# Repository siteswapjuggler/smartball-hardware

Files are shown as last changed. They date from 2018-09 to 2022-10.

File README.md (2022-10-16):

# Smartball project - hardware 

This repository contains the Smartball project hardware files: bom, schematics, board layout and 3D printed part.

## Open Source

All the technological development work made in the Smartball project is available under open source licenses. As we don't know yet about how we will deal with further development all of our hardwares will be published under Creative Commons BY-NC-SA and all of our softwares will be under GPL v3.

|Applying to|Licence|Logo|
|---|---|---|
|hardware|[Creatives Commons BY-NC-SA](http://creativecommons.org/licenses/by-nc-sa/4.0/)||
|software|[GPL v3](http://www.gnu.org/licenses/gpl.html)|GPL V3 (http://www.gnu.org/licenses/gpl.html)|

## Different boards

The project is an assembly of three boards: 2 led boards + 1 main board. It relies on the ESP-12F espressif breakout but could be used with ESP-12E or ESP-12F without any problem.

## Version history

v1.1 is the version product for the first prototypes and contains an minor error on USB Data Lines
v1.2 is the latest version, it correct the USB Data Lines error

## Linked repositories

This repository refers directly to its following siblings : 

- https://github.com/siteswapjuggler/smartball-firmware
- https://github.com/siteswapjuggler/smartball-externals
- https://github.com/siteswapjuggler/smartball-documents
- https://github.com/siteswapjuggler/smartball-imu

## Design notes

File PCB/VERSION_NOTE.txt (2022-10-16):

v1.0 - initial release
v1.1 - USB Footprint correction for PCBWays
v1.2 - Data+ and Data- correcteds

----------------------------------------------------------------

v2.0 - 14:20 new batch
v2.1 - Jive test batch with power path and capacitor correction 
v2.2 - Jive final batch with MCP1812AT intergration and ground plane optimisation

----------------------------------------------------------------

v3.0 - prefiguration for ESP32 version

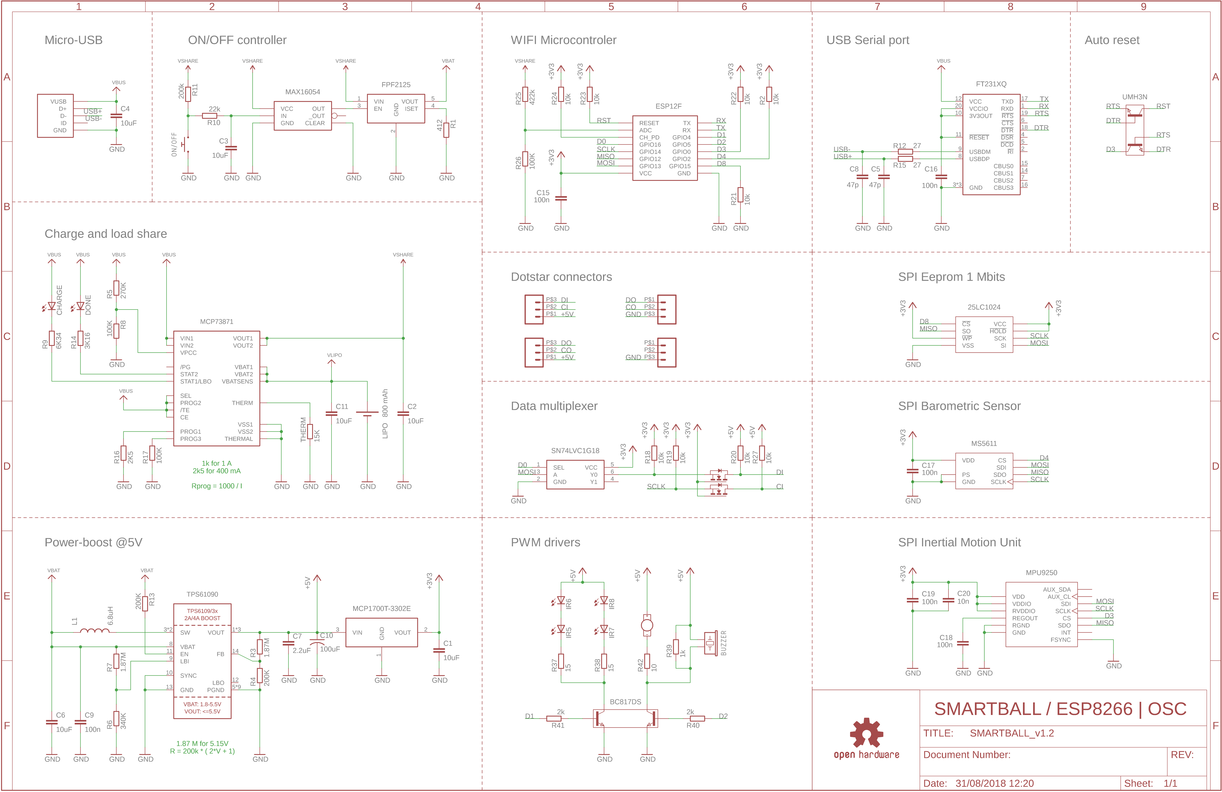
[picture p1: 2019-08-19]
PCB/docs/schematic_v1.2.png

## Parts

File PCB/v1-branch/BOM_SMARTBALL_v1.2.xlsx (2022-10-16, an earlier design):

SMARTBALL v2 - BILL OF MATERIAL
Type | Part | Value | Device | Package | NB | FOURNISSEUR | LIEN FOURNISSEUR
CHIPSET | IMU | - | MPU9250 | QFN24 | 1 | ALIEXPRESS | lien (https://fr.aliexpress.com/item/10PCS-X-100-New-INVENSENSE-MPU9250-9-AXIS-MEMS-Gyro-accelerometer-Compass-Sensor-MPU-9250/1726497480.html)
HARDWARE | BATTERY | 800 mAh | LiPo | 703035 | 1 | ALIEXPRESS | lien (https://www.aliexpress.com/item/10pcs-lot-3-7V-800mAh-703035-Lithium-Polymer-Li-Po-li-ion-Rechargeable-Battery-cells-For/32864173919.html)
HARDWARE | ESP12F | - | ESP12F | - | 1 | ALIEXPRESS | lien (https://fr.aliexpress.com/item/1PCS-Esp8266-WiFi-series-of-model-ESP-12-ESP-12F-esp12F-esp12-authenticity-guaranteed/32596555793.html)
HARDWARE | MOTOR | - | - | - | 1 | ALIEXPRESS | lien (https://fr.aliexpress.com/item/High-quality-100Pcs-10mm-x-3mm-disc-vibration-motor-vibrator-motor-game-console-handle-motor/32818196771.html)
HARDWARE | USB | - | USB_LEAD | - | 1 | ALIEXPRESS | lien (https://fr.aliexpress.com/item/25-cm-100-cm-200-cm-300-cm-Micro-USB-Rapide-Chargeur-C-ble-pour-Xiaomi/32899717419.html)
LED | LED | RGB | APA102C | 5050 | 6 | ALIEXPRESS | lien (https://fr.aliexpress.com/item/10-1000-Pieces-APA102-LEDs-Chips-APA-102C-SK9822-IC-SMD-5050-RGB-for-LED-Strip/32830624851.html)
CAPACITOR | CAPACITOR | 100 µF | TANTALUM | 1210 | 1 | FARNELL | 1432579
CAPACITOR | CAPACITOR | 10 nF | X7R | 0603 | 1 | FARNELL | 2896700
CAPACITOR | CAPACITOR | 2.2 µF | X7R | 0603 | 1 | FARNELL | 2346961
CAPACITOR | CAPACITOR | 47p | C0G / NP0 | 0603 | 2 | FARNELL | 2896692
CAPACITOR | CAPACITOR | 10 µF | X5R | 0603 | 6 | FARNELL | 2611923
CAPACITOR | CAPACITOR | 100 nF | X7R / 50V | 0603 | 6 | FARNELL | 2522435
CHIPSET | BAROMETER | - | MS5611 | QFN | - | FARNELL | 2362662
CHIPSET | BC817DS | - | BC817DS | SOT457R | 1 | FARNELL | 1757895
CHIPSET | BOOSTER | 5V | TPS61090RSAR | PVQFN-16 | 1 | FARNELL | 1207334
CHIPSET | CHARGER | 1S - 4.2V | MCP73871-2AAI | QFN20 | 1 | FARNELL | 1642487
CHIPSET | DUAL_NCH | - | 2N7002PS | SOT363 | 1 | FARNELL | 1859846
CHIPSET | DUAL_NPN | - | UMH3NFHATN | SOT363 | 1 | FARNELL | 2576211
CHIPSET | EEPROM | 1 Mbit | 25LC1024DFN-S | DFN-S | 1 | FARNELL | 1331391
CHIPSET | LATCH IC |  | MAX16054 | TSOT23-6 | 1 | FARNELL | 2515822
CHIPSET | MULTIPLEXER | 1 CH | SN74LVC1G18 | DCK | 1 | FARNELL | 2334935
CHIPSET | REGULATOR | 3V3 250 mA | MCP1700T | SOT23-3 | 1 | FARNELL | 1296592
CHIPSET | SERIAL USB | - | FT231X | QFN20 | 1 | FARNELL | 2081330
CHIPSET | SMART SWITCH | - | FPF2125 | SOT23-5 | 1 | FARNELL | 1228317
HARDWARE | BUTTON | OFF-(ON) | B3U-3000P-B | - | 1 | FARNELL | 1333656
HARDWARE | BUZZER | 4000 Hz | PKMCS0909E4000-R1 | - | 1 | FARNELL | 2529461
HARDWARE | USB | - | MOLEX_105017-0001 | - | 1 | FARNELL | 2293836
INDUCTOR | INDUCTOR | 6.8uH | ASPIAIG-S4035-6R8M-T | - | 1 | FARNELL | 2848352
LED | LED | Green |  | 0603 | 1 | FARNELL | 2099223
LED | LED | Orange |  | 0603 | 1 | FARNELL | 2099222
LED | LED | 850 nm | SFH4050 | - | 4 | FARNELL | 1441335
RESISTOR | RESISTOR | 412 | R-EU_R0402 | 0402 | 1 | FARNELL | 2302592
RESISTOR | RESISTOR | 15K | R-EU_R0402 | 0402 | 1 | FARNELL | 2302754
RESISTOR | RESISTOR | 22K | R-EU_R0402 | 0402 | 1 | FARNELL | 2302772
RESISTOR | RESISTOR | 270K | R-EU_R0402 | 0402 | 1 | FARNELL | 2302885
RESISTOR | RESISTOR | 2K55 | R-EU_R0402 | 0402 | 1 | FARNELL | 2302679
RESISTOR | RESISTOR | 340K | R-EU_R0402 | 0402 | 1 | FARNELL | 2694598
RESISTOR | RESISTOR | 3K16 | R-EU_R0402 | 0402 | 1 | FARNELL | 2302687
RESISTOR | RESISTOR | 422K | R-EU_R0402 | 0402 | 1 | FARNELL | 2302909
RESISTOR | RESISTOR | 6K34 | R-EU_R0402 | 0402 | 1 | FARNELL | 2302721
RESISTOR | RESISTOR | 10 / 250 mW | R-EU_R0402 | 0402 | 1 | FARNELL | 2502794
RESISTOR | RESISTOR | 1K | R-EU_R0402 | 0402 | 1 | FARNELL | 2302638
RESISTOR | RESISTOR | 27 | R-EU_R0402 | 0402 | 2 | FARNELL | 2302462
RESISTOR | RESISTOR | 1M87 / 1% | R-EU_R0402 | 0402 | 2 | FARNELL | 2141071
RESISTOR | RESISTOR | 15 / 125 mW | R-EU_R0402 | 0402 | 2 | FARNELL | 1738826
RESISTOR | RESISTOR | 2K | R-EU_R0402 | 0402 | 2 | FARNELL | 2059132
RESISTOR | RESISTOR | 100K | R-EU_R0402 | 0402 | 3 | FARNELL | 2302839
RESISTOR | RESISTOR | 200K | R-EU_R0402 | 0402 | 3 | FARNELL | 2059185
RESISTOR | RESISTOR | 10K | R-EU_R0402 | 0402 | 9 | FARNELL | 2302739
TOOLS | GLUE | - | LOCTITE 406 | - | 1 | FARNELL | 1370126
TOOLS | GLUE | - | LOCTITE 770 | - | 1 | FARNELL | 1370163
HARDWARE | HARDWARE | - | COQUE_BALLE | - | 1 | LA RIBOULDINGUE | -
HARDWARE | PCB | - | MAIN_PCB | - | 1 | PCB_WAY | lien (https://www.pcbway.com/)
HARDWARE | PCB | - | LED_PCB | - | 2 | PCB_WAY | lien (https://www.pcbway.com/)
HARDWARE | FEMALE_HEADER | 2 mm | SAMTEC SMM-103-02-S-S | SMD | 4 | SAMTEC | lien (https://www.samtec.com/products/smm)
HARDWARE | MALE_HEADER | 2 mm | SAMTEC TW-03-02-T-S-150-120 | TH | 4 | SAMTEC | lien (https://www.samtec.com/products/tw-th)
HARDWARE | 3D_PRINT | - | SUPPORT_PCB | - | 1 | SELF_PRODUCTION | -
HARDWARE | 3D_PRINT | - | SUPPORT_LEDS | - | 2 | SELF_PRODUCTION | -
 | Total |  |  |  | 100

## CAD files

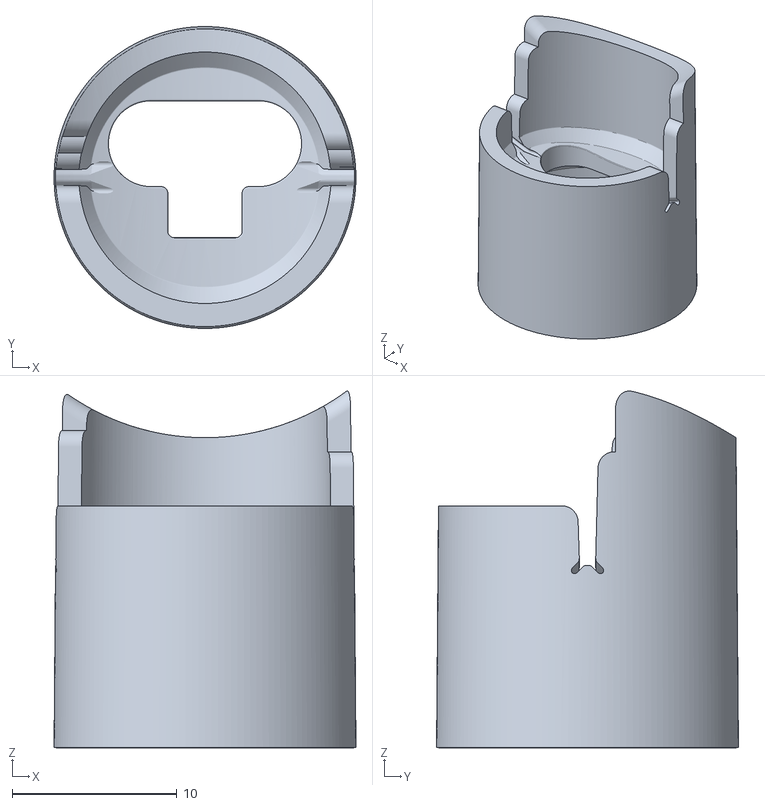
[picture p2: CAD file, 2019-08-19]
STL/pcb_support_v5.stl
18.3 x 18.3 x 21.6

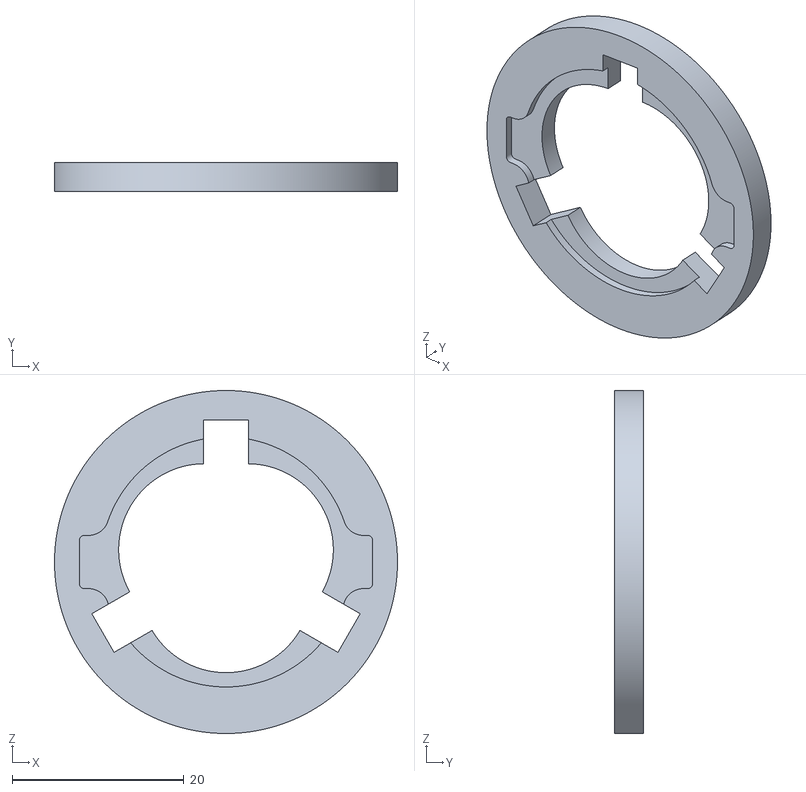
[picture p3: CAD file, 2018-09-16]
STL/led_placement.stl
40.0 x 3.40 x 40.0

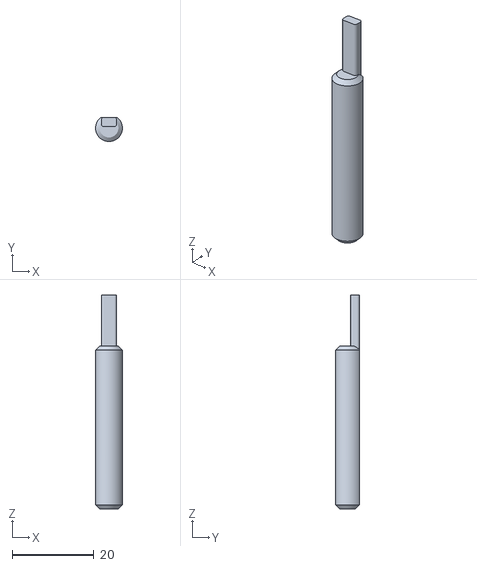
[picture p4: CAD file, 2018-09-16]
STL/starter_tool.stl
6.60 x 5.90 x 52.5

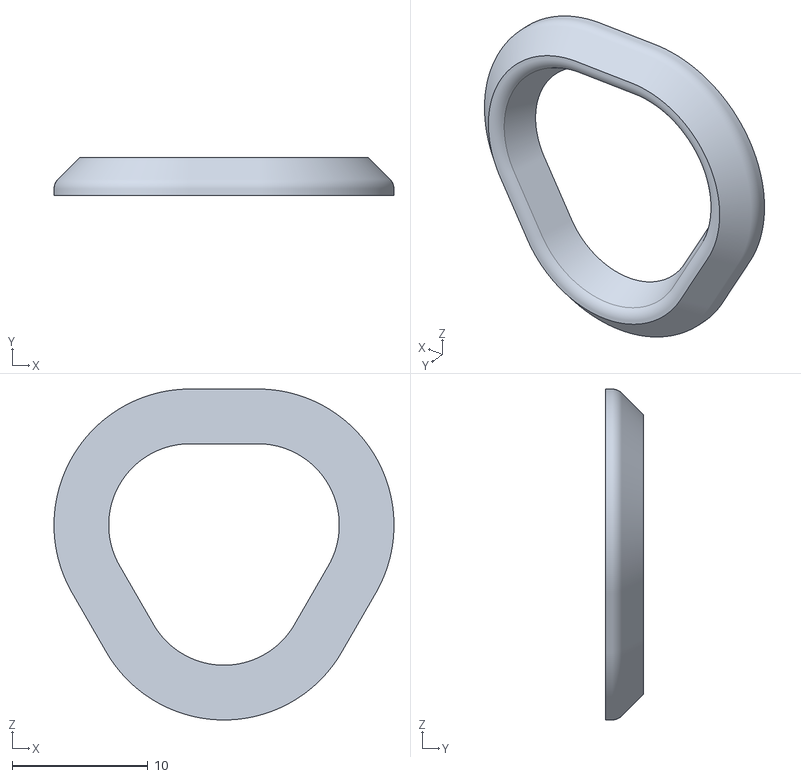
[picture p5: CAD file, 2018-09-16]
STL/leds_support.stl
25.0 x 2.83 x 24.4

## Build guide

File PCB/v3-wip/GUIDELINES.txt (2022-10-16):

USB-C
MAX1650 Power Management
Better Buck Boost Converter and 3V3 LDO
FPC for APA107 and IR Leds
Better selection for motor and buzzer
New IMU because of MPU9255 not being available anymore
Optimised Antenna
ESP32

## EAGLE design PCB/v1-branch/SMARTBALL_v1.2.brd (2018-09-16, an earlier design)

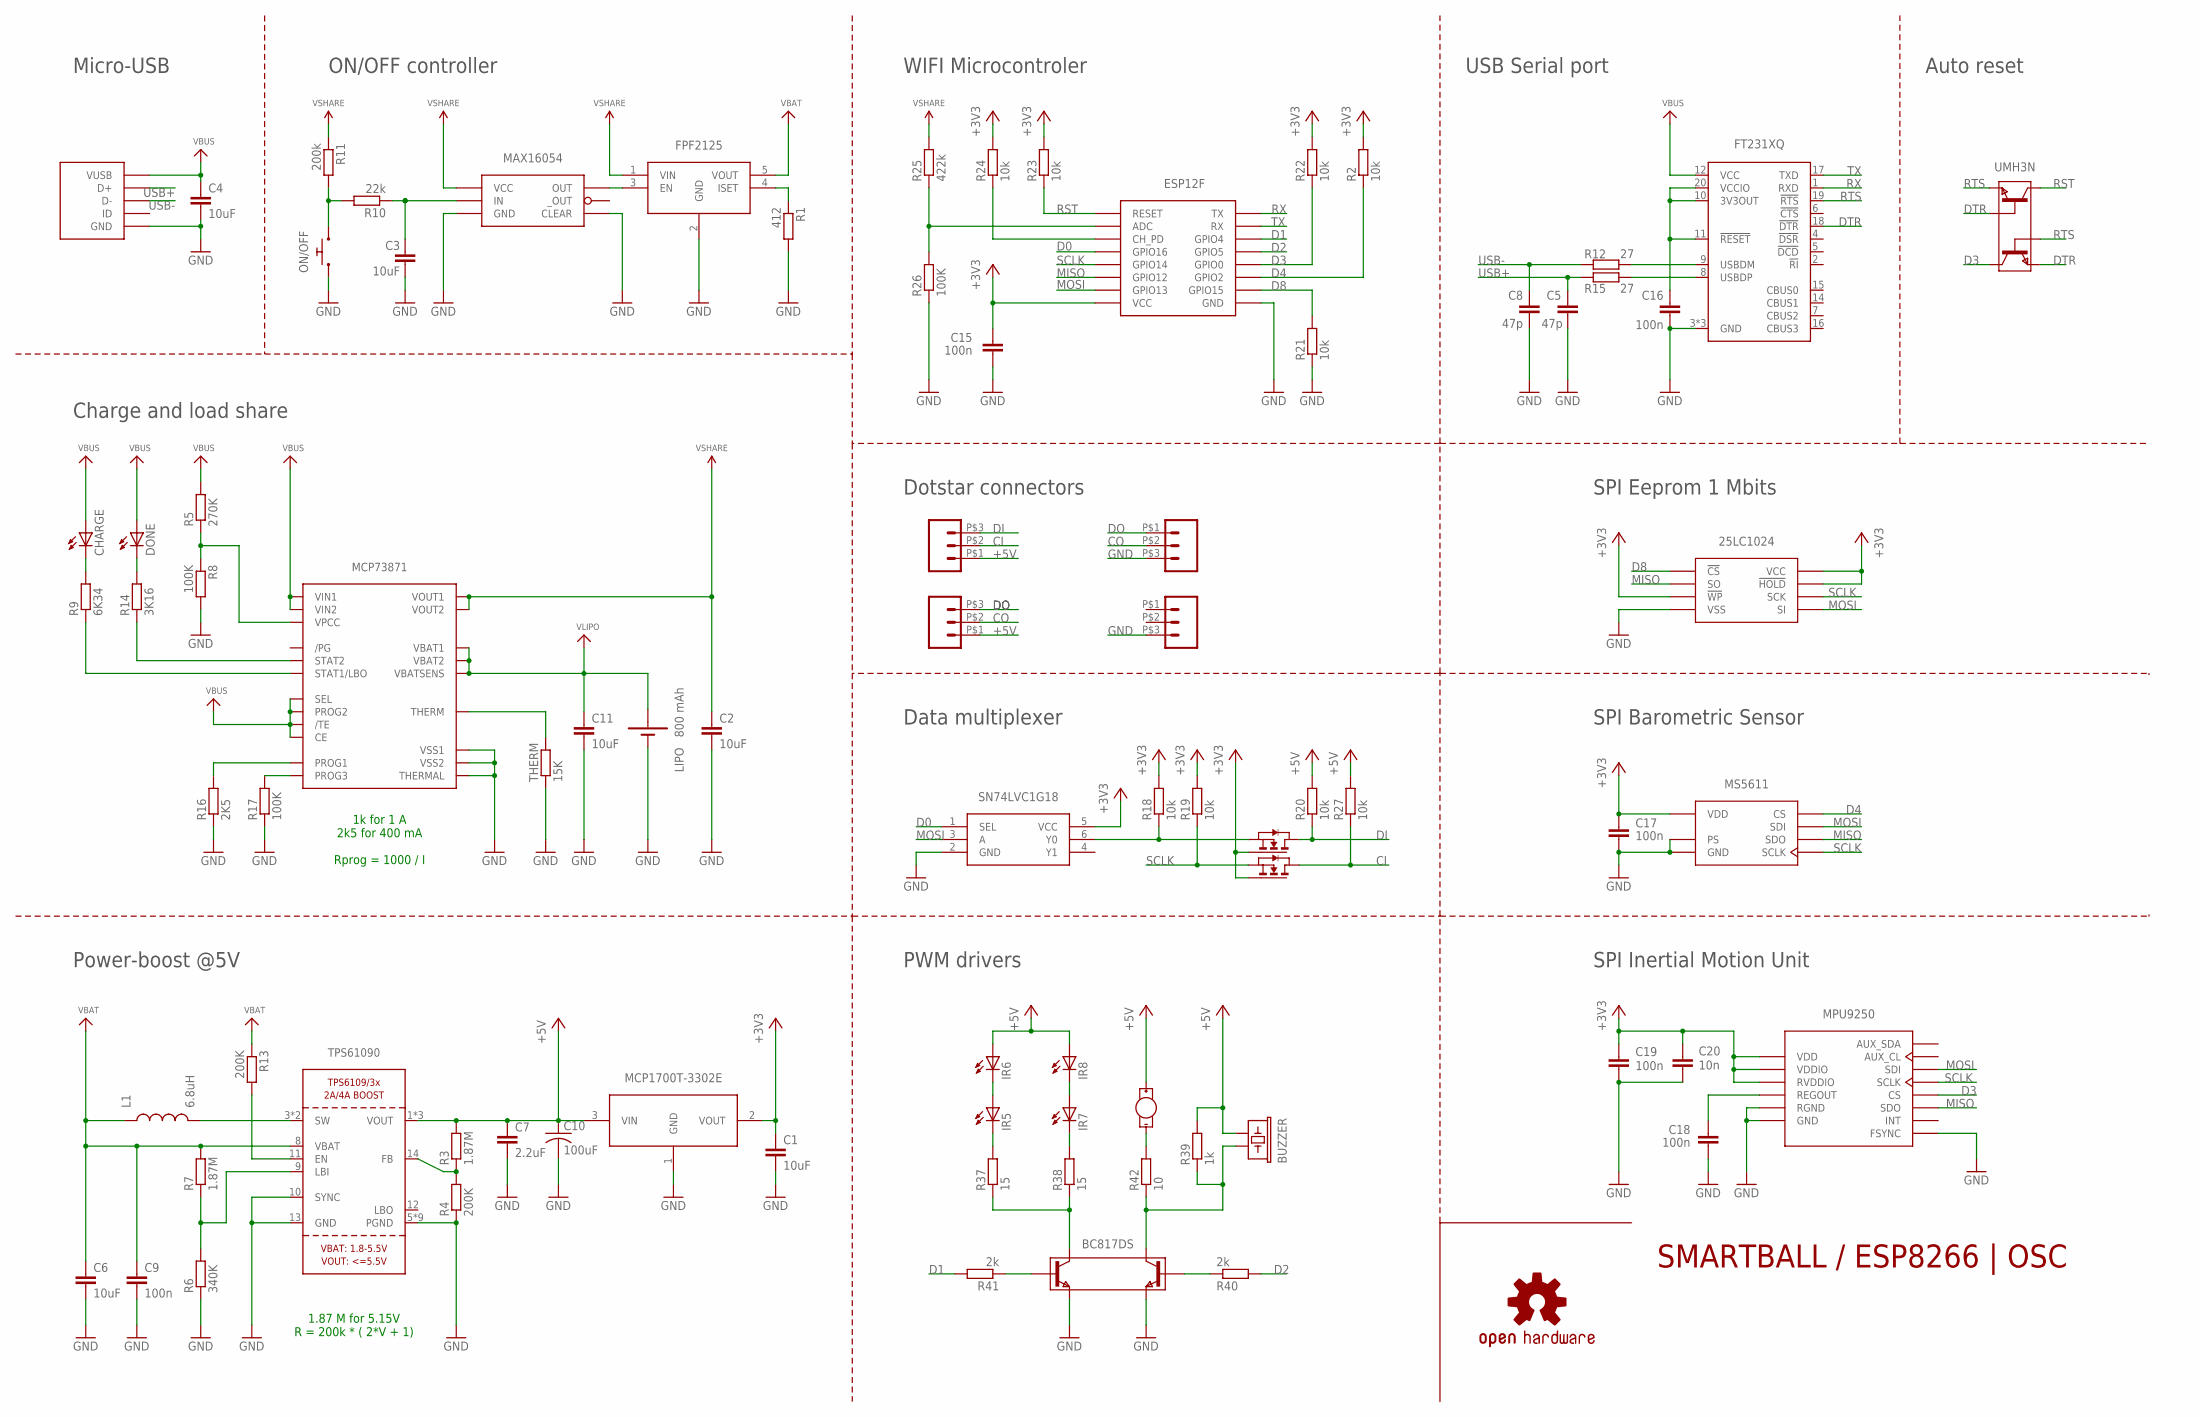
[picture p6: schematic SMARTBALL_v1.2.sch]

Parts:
BC817DS: BC817DS; SOT457R_PHILIPS
BUZZER: BUZZER_PKMCS0909E4000-R1
C1, C2, C3, C4, C6, C11: 10uF; C0603K
C5, C8: 47p; C0603K
C7: 2.2uF; C0603K
C9, C15, C16, C17, C18, C19: 100n; C0603K
C10: 100uF; C1210
C20: 10n; C0603K
CHARGE: KINGBRIGHT_16X08
DONE: KINGBRIGHT_16X08
ESP12F: ESP12
FT231XQ: FT231X; QFN20
IR5, IR6, IR7, IR8: LED-SFH4050; SFH4050
L1: 6.8uH; ASPIAIG-S4035
LIPO: BATTERY_CONNECTOR; MOTOR_CONNECTOR
LOGO1: OSHW-LOGOL; OSHW-LOGO-L
MCP73871: MCP73871; QFN20_4MM
MOTOR: MOTOR_CONNECTOR
ON/OFF: B3U-3000P-B
R1: 412; R0402
R2, R18, R19, R20, R21, R22, R23, R24, R27: 10k; R0402
R3, R7: 1.87M; R0402
R4, R13: 200K; R0402
R5: 270K; R0402
R6: 340K; R0402
R8, R17, R26: 100K; R0402
R9: 6K34; R0402
R10: 22k; R0402
R11: 200k; R0402
R12, R15: 27; R0402
R14: 3K16; R0402
R16: 2K5; R0402
R25: 422k; R0402
R37, R38: 15; R0402
R39: 1k; R0402
R40, R41: 2k; R0402
R42: 10; R0402
THERM: 15K; R0402
TPS61090: TPS61090RSAR; PVQFN-16
U$1: MOLEX-USB
U$2: FPF2125; SOT23-5
U$3: MCP1700T; SOT23-3
U$5, U$6, U$14, U$15: CONN_03_SMD; CONN03_SMD
U$12: MAX16054; TSOT23-6
U$16: 25LC1024DFN-S; DFN-S
U$17: MS5611; MS5611-QFN
U$20: SN74LVC1G18; DCK_R-PDSO-G6
U$21: MPU-9250QFN24G; QFN24G-0.4-3X3MM
U$22: 2N7002PS; SOT363_PHILIPS
UMH3N: UMH3N; SOT363_PHILIPS

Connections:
+3V3: C1.1, C15.1, C17.1, C19.1, C20.2, ESP12F.VCC, R2.2, R18.2, R19.2, R22.2, R23.2, R24.2, U$3.2 (VOUT), U$16.3 (!WP), U$16.7 (!HOLD), U$16.8 (VCC), U$17.P$1 (VDD), U$20.5 (VCC), U$21.1 (RVDDIO), U$21.8 (VDDIO), U$21.13 (VDD), U$22.2 (G1), U$22.5 (G2)
+5V: BUZZER.P$1 (1), C7.1, C10.1, IR6.P$1 (A), IR8.P$1 (A), MOTOR.+, R3.2, R20.2, R27.2, R39.2, TPS61090.1 (VOUT), TPS61090.15 (VOUT), TPS61090.16 (VOUT), U$3.3 (VIN), U$5.P$1 (1), U$15.P$1 (1)
CI: R27.1, U$5.P$2 (2), U$22.3 (D2)
CO: U$6.P$2 (2), U$15.P$2 (2)
D0: ESP12F.GPIO16, U$20.1 (SEL)
D1: ESP12F.GPIO4, R41.2
D2: ESP12F.GPIO5, R40.2
D3: ESP12F.GPIO0, R22.1, U$21.22 (CS), UMH3N.3 (C2)
D4: ESP12F.GPIO2, R2.1, U$17.P$4 (CS), U$17.P$5 (CS)
D8: ESP12F.GPIO15, R21.2, U$16.1 (!CS)
DI: R20.1, U$5.P$3 (3), U$22.6 (D1)
DO: U$6.P$1 (1), U$15.P$3 (3)
DTR: FT231XQ.18 (!DTR), UMH3N.2 (B1), UMH3N.4 (E2)
EN1: ESP12F.CH_PD, R24.1
ENABLE: R13.2, TPS61090.11 (EN)
GND: BC817DS.1 (E1), BC817DS.4 (E2), C1.2, C2.2, C3.2, C4.2, C5.2, C6.2, C7.2, C8.2, C9.2, C10.2, C11.2, C15.2, C16.2, C17.2, C18.2, C19.2, C20.1, ESP12F.GND, FT231XQ.3 (GND), FT231XQ.13 (GND), FT231XQ.EXP (GND), LIPO.-, MCP73871.P$10 (VSS1), MCP73871.P$11 (VSS2), MCP73871.P$21 (THERMAL), ON/OFF.P$1 (1), R1.2, R4.1, R6.1, R8.2, R16.1, R17.1, R21.1, R26.1, THERM.1, TPS61090.5 (PGND), TPS61090.6 (PGND), TPS61090.7 (PGND), TPS61090.10 (SYNC), TPS61090.13 (GND), TPS61090.P$18 (PGND), TPS61090.P$19 (PGND), TPS61090.P$20 (PGND), TPS61090.P$21 (PGND), TPS61090.P$22 (PGND), TPS61090.THERMAL (PGND), U$1.GND, U$1.P$1 (GND), U$1.P$11 (GND), U$1.SHELL1 (GND), U$1.SHELL2 (GND), U$1.SHELL5 (GND), U$1.SHELL6 (GND), U$2.2 (GND), U$3.1 (GND), U$6.P$3 (3), U$12.CLEAR, U$12.GND, U$14.P$3 (3), U$16.4 (VSS), U$17.P$2 (PS), U$17.P$3 (GND), U$20.2 (GND), U$21.11 (FSYNC), U$21.18 (GND), U$21.20 (RGND)
MISO: ESP12F.GPIO12, U$16.2 (SO), U$17.P$6 (SDO), U$21.9 (SDO)
MOSI: ESP12F.GPIO13, U$16.5 (SI), U$17.P$7 (SDI), U$20.3 (A), U$21.24 (SDI)
unnamed: U$2.3 (EN), U$12.OUT
unnamed: R1.1, U$2.4 (ISET)
unnamed: MCP73871.P$2 (VPCC), R5.1, R8.1
unnamed: MCP73871.P$13 (PROG1), R16.2
unnamed: FT231XQ.9 (USBDM), R12.2
unnamed: FT231XQ.8 (USBDP), R15.2
unnamed: ON/OFF.P$2 (2), R10.2, R11.2
unnamed: C3.1, R10.1, U$12.IN
unnamed: R18.1, U$20.6 (Y0), U$22.1 (S1)
unnamed: ESP12F.ADC, R25.1, R26.2
unnamed: L1.P$2 (2), TPS61090.3 (SW), TPS61090.4 (SW)
unnamed: R6.2, R7.1, TPS61090.9 (LBI)
unnamed: R3.1, R4.2, TPS61090.14 (FB)
unnamed: MCP73871.P$7 (STAT2), R14.1
unnamed: MCP73871.P$8 (STAT1/LBO), R9.1
unnamed: MCP73871.P$5 (THERM), THERM.2
unnamed: DONE.CATHODE (C), R14.2
unnamed: CHARGE.CATHODE (C), R9.2
unnamed: MCP73871.P$12 (PROG3), R17.2
unnamed: IR5.P$2 (C), R37.2
unnamed: IR5.P$1 (A), IR6.P$2 (C)
unnamed: BC817DS.3 (C2), R37.1, R38.1
unnamed: IR7.P$2 (C), R38.2
unnamed: IR7.P$1 (A), IR8.P$2 (C)
unnamed: BC817DS.6 (C1), BUZZER.P$2 (2), R39.1, R42.1
unnamed: MOTOR.-, R42.2
unnamed: BC817DS.5 (B2), R41.1
unnamed: BC817DS.2 (B1), R40.1
REGOUT1: C18.1, U$21.10 (REGOUT)
RST: ESP12F.RESET, R23.1, UMH3N.6 (C1)
RTS: FT231XQ.19 (!RTS), UMH3N.1 (E1), UMH3N.5 (B2)
RX: ESP12F.TX, FT231XQ.1 (RXD)
SCLK: ESP12F.GPIO14, R19.1, U$16.6 (SCK), U$17.P$8 (SCLK), U$21.23 (SCLK), U$22.4 (S2)
TX: ESP12F.RX, FT231XQ.17 (TXD)
USB+: C5.1, R15.1, U$1.D+
USB-: C8.1, R12.1, U$1.D-
VBAT: C6.1, C9.1, L1.P$1 (1), R7.2, R13.1, TPS61090.8 (VBAT), U$2.5 (VOUT)
VBUS: C4.1, CHARGE.ANODE (A), DONE.ANODE (A), FT231XQ.12 (VCC), MCP73871.P$3 (SEL), MCP73871.P$4 (PROG2), MCP73871.P$9 (/TE), MCP73871.P$17 (CE), MCP73871.P$18 (VIN1), MCP73871.P$19 (VIN2), R5.2, U$1.VUSB
VCCIO1: C16.1, FT231XQ.10 (3V3OUT), FT231XQ.11 (!RESET), FT231XQ.20 (VCCIO)
VLIPO: C11.1, LIPO.+, MCP73871.P$14 (VBAT1), MCP73871.P$15 (VBAT2), MCP73871.P$16 (VBATSENS)
VSHARE: C2.1, MCP73871.P$1 (VOUT1), MCP73871.P$20 (VOUT2), R11.1, R25.2, U$2.1 (VIN), U$12.VCC

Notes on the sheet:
SMARTBALL / ESP8266 | OSC
MCP1700T-3302E
1k for 1 A 2k5 for 400 mA Rprog = 1000 / I
Micro-USB
Charge and load share
ON/OFF controller
USB Serial port
WIFI Microcontroler
Auto reset
Data multiplexer
Dotstar connectors
PWM drivers
Power-boost @5V
SPI Inertial Motion Unit
SPI Eeprom 1 Mbits
SPI Barometric Sensor
800 mAh
MAX16054
FPF2125
SN74LVC1G18
1.87 M for 5.15V R = 200k * ( 2*V + 1)

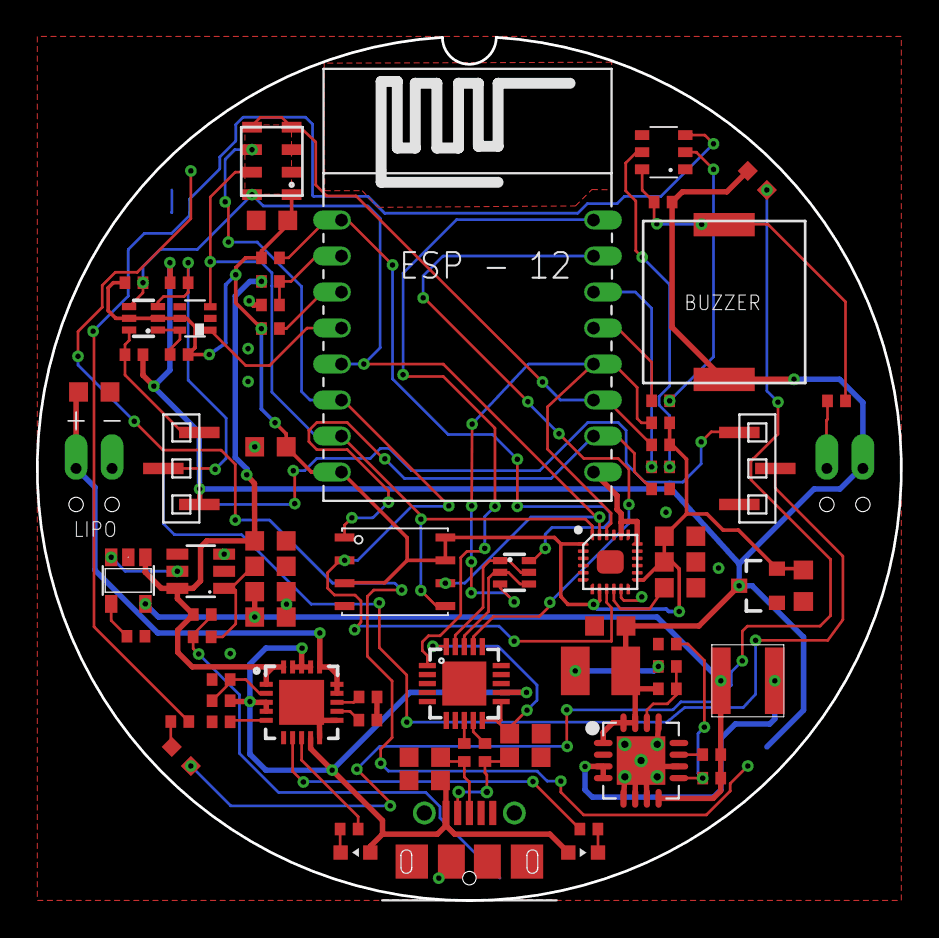
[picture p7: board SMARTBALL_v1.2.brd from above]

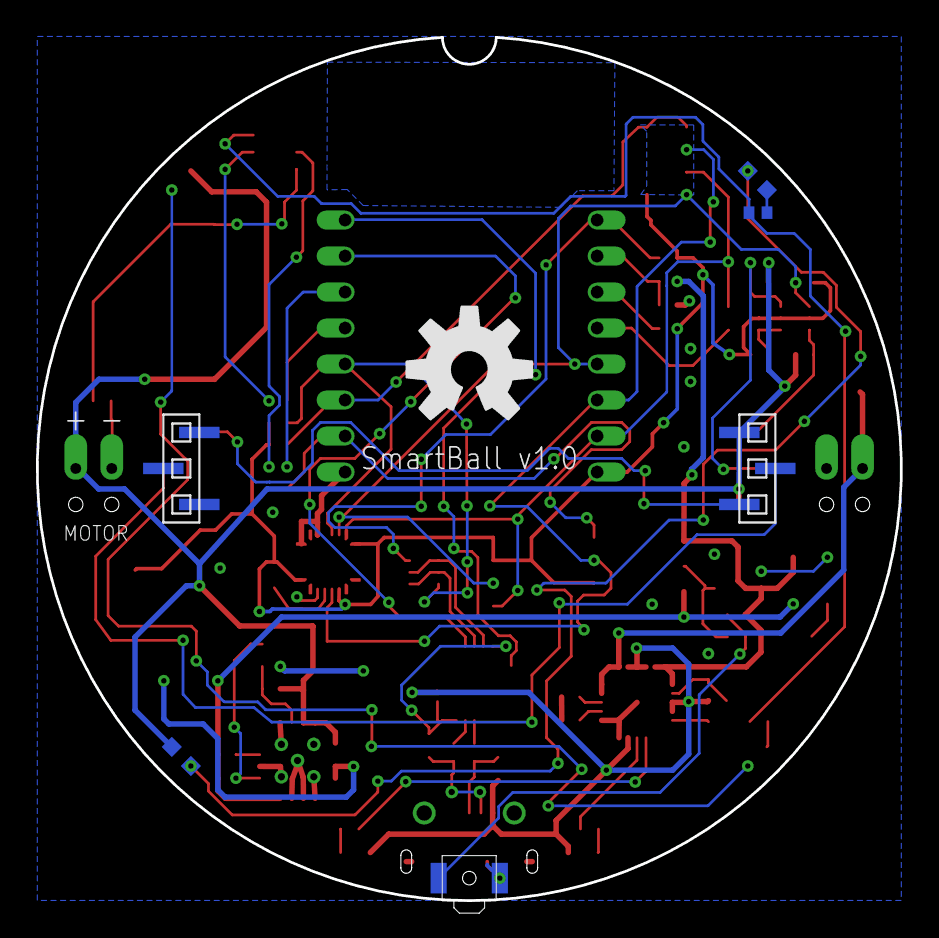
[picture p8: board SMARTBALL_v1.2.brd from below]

Board: 2 copper layers, 48.0 x 48.0 mm, 82 parts (8 on the bottom side), 59 nets.

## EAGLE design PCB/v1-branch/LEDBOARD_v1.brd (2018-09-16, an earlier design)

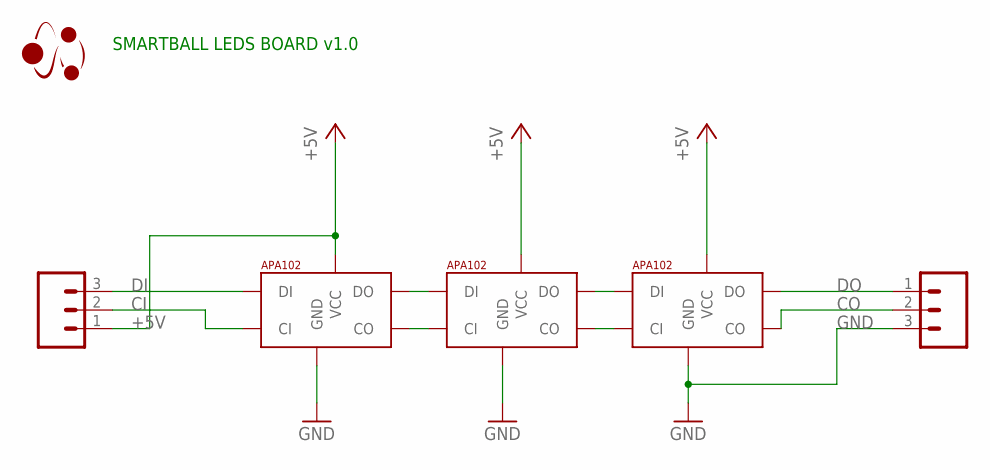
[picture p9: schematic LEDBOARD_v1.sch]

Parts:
U$1, U$2, U$3: APA102; APA102_5050_SB
U$4: LOGO_SMARTBALL; SMARTBALL_LOGO
U$5, U$6: CONN_03_SMDCONN03_SMD_MALE; CONN03_SMD_MALE

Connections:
+5V: U$1.VCC, U$2.VCC, U$3.VCC, U$5.1
CI: U$1.CI, U$1.CI2 (CI), U$5.2
CO: U$3.CO, U$6.2
DI: U$1.DI, U$1.DI2 (DI), U$5.3
DO: U$3.DO, U$6.1
GND: U$1.GND, U$1.GND2 (GND), U$2.GND, U$2.GND2 (GND), U$3.GND, U$3.GND2 (GND), U$6.3
unnamed: U$1.DO, U$2.DI, U$2.DI2 (DI)
unnamed: U$1.CO, U$2.CI, U$2.CI2 (CI)
unnamed: U$2.DO, U$3.DI, U$3.DI2 (DI)
unnamed: U$2.CO, U$3.CI, U$3.CI2 (CI)

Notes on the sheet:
SMARTBALL LEDS BOARD v1.0

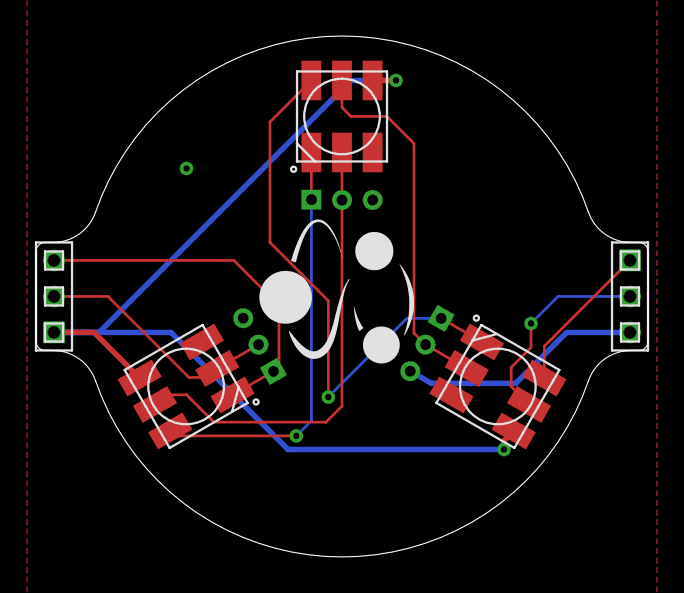
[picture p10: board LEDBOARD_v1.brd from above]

Board: 2 copper layers, 34.0 x 28.9 mm, 6 parts (0 on the bottom side), 10 nets.

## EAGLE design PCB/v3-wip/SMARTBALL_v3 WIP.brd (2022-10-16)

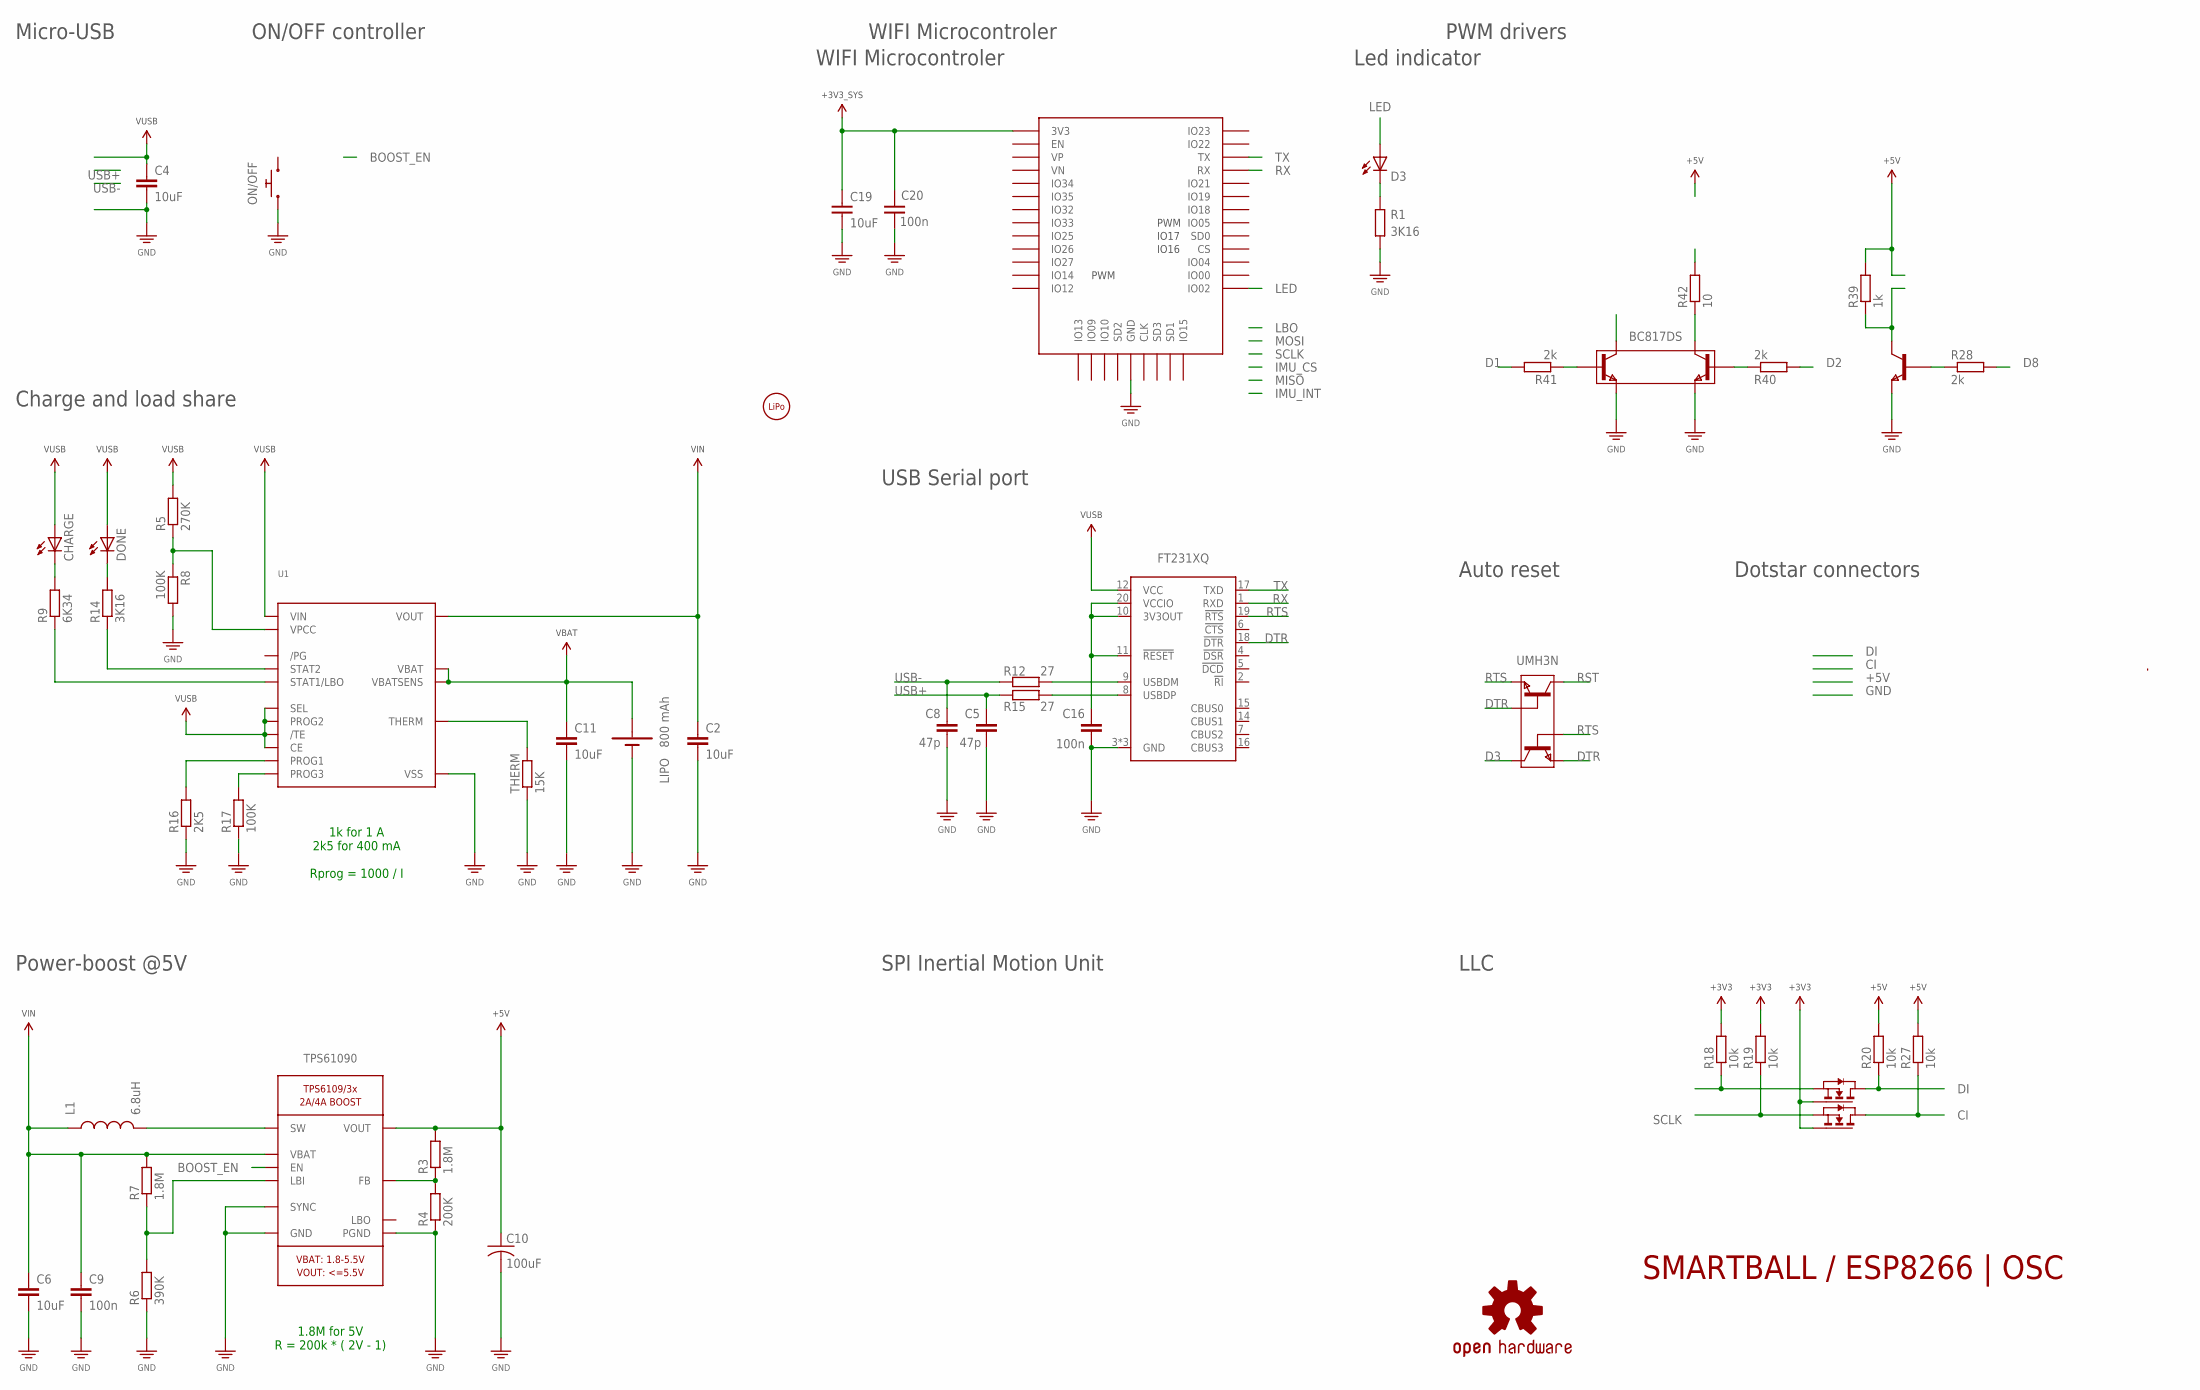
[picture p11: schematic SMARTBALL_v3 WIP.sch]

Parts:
BC817DS: SOT_BC817DS; SOT457R_PHILIPS
C2, C4, C6, C11, C19: 10uF; C0603
C5, C8: 47p; C0603
C9, C16, C20: 100n; C0603
C10: 100uF; C1210
CHARGE: LED_KINGBRIGHT_16X08
D3: Blue; LED_KINGBRIGHT_16X08
DONE: LED_KINGBRIGHT_16X08
FT231XQ: QFN_FT231X; QFN20
L1: 6.8uH; IND_ASPIAIG-S4035
LIPO: CONN_BATTERY; CONN_WIRES
LOGO1: LOGO_OSHWL; LOGO_OSHW
ON/OFF: BUT_KMR6
R1, R14: 3K16; R0402
R3, R7: 1.8M; R0402
R4: 200K; R0402
R5: 270K; R0402
R6: 390K; R0402
R8, R17: 100K; R0402
R9: 6K34; R0402
R12, R15: 27; R0402
R16: 2K5; R0402
R18, R19, R20, R27: 10k; R0402
R28, R40, R41: 2k; R0402
R39: 1k; R0402
R42: 10; R0402
THERM: 15K; R0402
TPS61090: TPS61090RSAR; QFN16
U1: QFN_MCP73871; QFN20
U6: ESP-MICRO32
U$22: SOT_2N7002PS; SOT363
U$28: SOT_SBC847AWT1G; SOT323
U$29: BATT_BODY
UMH3N: SOT_UMH3N; SOT363

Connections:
+3V3: R18.2, R19.2, U$22.2 (G1), U$22.5 (G2)
+3V3_SYS: C19.1, C20.1, U6.2 (3V3)
+5V: C10.1, R3.2, R20.2, R27.2, R39.2, TPS61090.1 (VOUT), TPS61090.15 (VOUT), TPS61090.16 (VOUT)
B1: BC817DS.5 (B2), R41.1
B2: BC817DS.2 (B1), R40.1
B3: R28.1, U$28.1 (B)
BOOST_EN: TPS61090.11 (EN)
C1: BC817DS.3 (C2)
C2: BC817DS.6 (C1), R42.1
C3: R39.1, U$28.3 (C)
CI: R27.1, U$22.3 (D2)
D1: R41.2
D2: R40.2
D3: UMH3N.3 (C2)
D8: R28.2
DI: R20.1, U$22.6 (D1)
DTR: FT231XQ.18 (!DTR), UMH3N.2 (B1), UMH3N.4 (E2)
FB: R3.1, R4.2, TPS61090.14 (FB)
GND: BC817DS.1 (E1), BC817DS.4 (E2), C2.2, C4.2, C5.2, C6.2, C8.2, C9.2, C10.2, C11.2, C16.2, C19.2, C20.2, FT231XQ.3 (GND), FT231XQ.13 (GND), FT231XQ.EXP (GND), LIPO.GND, ON/OFF.1, ON/OFF.4 (1), R1.1, R4.1, R6.1, R8.2, R16.1, R17.1, THERM.1, TPS61090.5 (PGND), TPS61090.6 (PGND), TPS61090.7 (PGND), TPS61090.10 (SYNC), TPS61090.13 (GND), TPS61090.PAD (PGND), U1.10 (VSS), U1.11 (VSS), U1.EXP (VSS), U6.1 (GND), U6.15 (GND), U6.38 (GND), U$28.2 (E)
LBI: R6.2, R7.1, TPS61090.9 (LBI)
LED: D3.1 (A), U6.24 (IO02)
LED1: DONE.2 (C), R14.2
LED2: CHARGE.2 (C), R9.2
LED3: D3.2 (C), R1.2
MOT: R42.2
PROG1: R16.2, U1.13 (PROG1)
PROG3: R17.2, U1.12 (PROG3)
RST: UMH3N.6 (C1)
RTS: FT231XQ.19 (!RTS), UMH3N.1 (E1), UMH3N.5 (B2)
RX: FT231XQ.1 (RXD), U6.34 (RX)
SCLK: R19.1, U$22.4 (S2)
STAT1: R9.1, U1.8 (STAT1/LBO)
STAT2: R14.1, U1.7 (STAT2)
SW: L1.2, TPS61090.3 (SW), TPS61090.4 (SW)
THERM: THERM.2, U1.5 (THERM)
TX: FT231XQ.17 (TXD), U6.35 (TX)
USB+: C5.1, R15.1
USB-: C8.1, R12.1
USBDM: FT231XQ.9 (USBDM), R12.2
USBDP: FT231XQ.8 (USBDP), R15.2
VBAT: C11.1, LIPO.VCC (VBAT), U1.14 (VBAT), U1.15 (VBAT), U1.16 (VBATSENS)
VCCIO1: C16.1, FT231XQ.10 (3V3OUT), FT231XQ.11 (!RESET), FT231XQ.20 (VCCIO)
VIN: C2.1, C6.1, C9.1, L1.1, R7.2, TPS61090.8 (VBAT), U1.1 (VOUT), U1.20 (VOUT)
VPCC: R5.1, R8.1, U1.2 (VPCC)
VUSB: C4.1, CHARGE.1 (A), DONE.1 (A), FT231XQ.12 (VCC), R5.2, U1.3 (SEL), U1.4 (PROG2), U1.9 (/TE), U1.17 (CE), U1.18 (VIN), U1.19 (VIN)
Y0: R18.1, U$22.1 (S1)

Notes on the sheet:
SMARTBALL / ESP8266 | OSC
1k for 1 A 2k5 for 400 mA Rprog = 1000 / I
Micro-USB
Charge and load share
ON/OFF controller
USB Serial port
WIFI Microcontroler
Auto reset
LLC
Dotstar connectors
PWM drivers
Power-boost @5V
SPI Inertial Motion Unit
800 mAh
1.8M for 5V R = 200k * ( 2V - 1)
Led indicator
IO17
IO16
PWM

Board: 2 copper layers, 50 parts (4 on the bottom side), 38 nets, no tracks yet.

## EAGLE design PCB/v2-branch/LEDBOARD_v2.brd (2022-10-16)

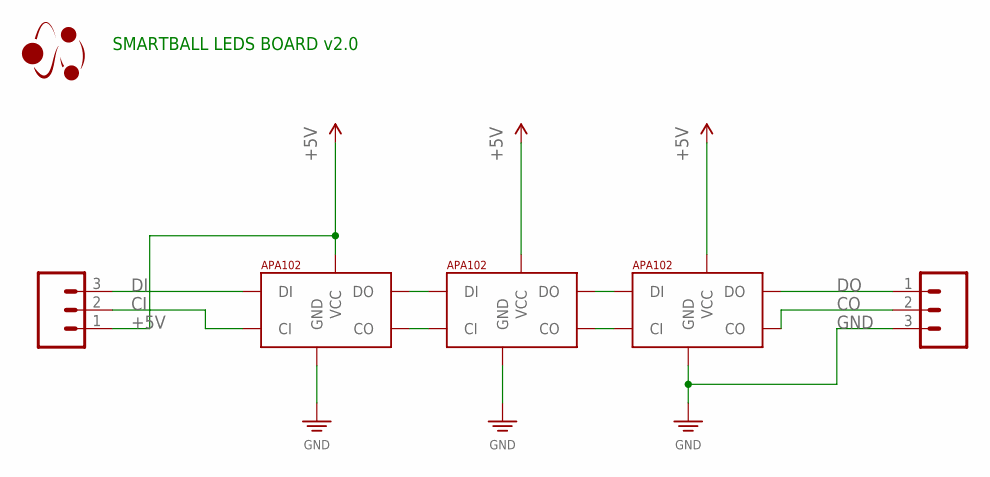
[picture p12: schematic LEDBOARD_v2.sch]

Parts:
L1, L2, L3: APA102; APA102_5050_SB
U$4: LOGO_SMARTBALL; SMARTBALL_LOGO
U$5, U$6: CONN_03_SMD_MALECONN03_SMD_MALE; CONN03_SMD_MALE

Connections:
+5V: L1.4 (VCC), L2.4 (VCC), L3.4 (VCC), U$5.1
CI: L1.2 (CI), L1.CI2 (CI), U$5.2
CO: L3.5 (CO), U$6.2
DI: L1.1 (DI), L1.DI2 (DI), U$5.3
DO: L3.6 (DO), U$6.1
GND: L1.3 (GND), L1.GND2 (GND), L2.3 (GND), L2.GND2 (GND), L3.3 (GND), L3.GND2 (GND), U$6.3
unnamed: L1.6 (DO), L2.1 (DI), L2.DI2 (DI)
unnamed: L1.5 (CO), L2.2 (CI), L2.CI2 (CI)
unnamed: L2.6 (DO), L3.1 (DI), L3.DI2 (DI)
unnamed: L2.5 (CO), L3.2 (CI), L3.CI2 (CI)

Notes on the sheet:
SMARTBALL LEDS BOARD v2.0

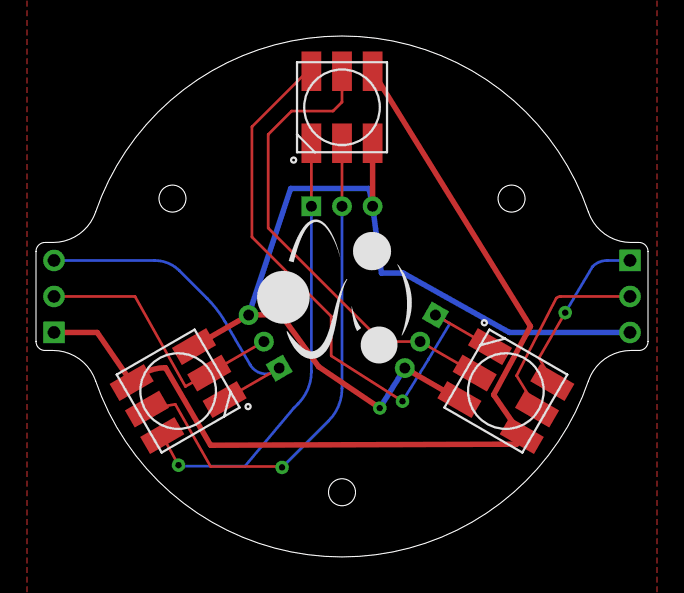
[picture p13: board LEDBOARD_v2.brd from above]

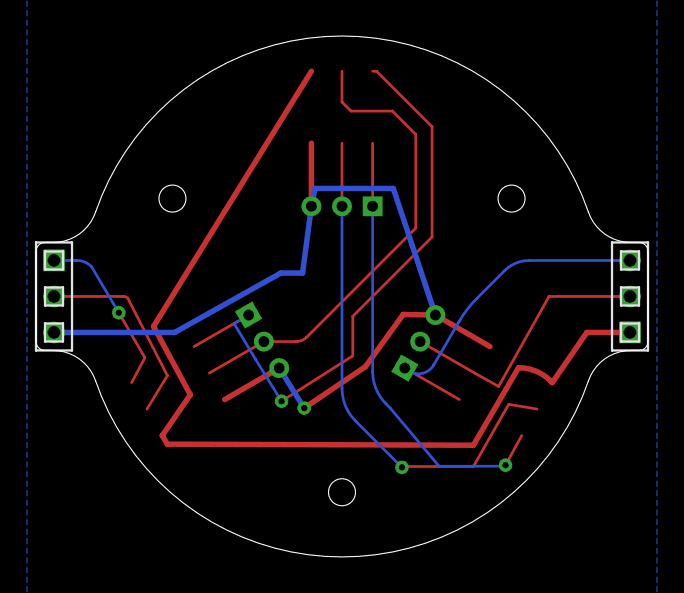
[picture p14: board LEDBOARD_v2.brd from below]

Board: 2 copper layers, 34.0 x 28.9 mm, 6 parts (2 on the bottom side), 10 nets.

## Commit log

2019-08-19 PCB support v5
    [pcb_support.stl, pcb_support_v5.stl]
2019-08-19 schematic update
2022-10-16 loads of change since v1
    [BOM_SMARTBALL_v1.2.xlsx, BOM_SMARTBALL_v2.xlsx, LEDBOARD_v2.brd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]
2022-10-16 folder by version
    [BOM_SMARTBALL_v1.2.xlsx, LEDBOARD_v1.brd, LEDBOARD_v1.sch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]

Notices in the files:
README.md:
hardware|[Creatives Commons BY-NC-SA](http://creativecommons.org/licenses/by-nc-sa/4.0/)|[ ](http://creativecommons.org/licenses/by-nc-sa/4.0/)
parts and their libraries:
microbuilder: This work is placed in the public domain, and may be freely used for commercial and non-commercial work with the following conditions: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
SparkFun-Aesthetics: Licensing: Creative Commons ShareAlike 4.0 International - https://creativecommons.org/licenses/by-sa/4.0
